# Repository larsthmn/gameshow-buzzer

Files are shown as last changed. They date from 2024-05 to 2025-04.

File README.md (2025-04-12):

# Gameshow Buzzer and Soundboard

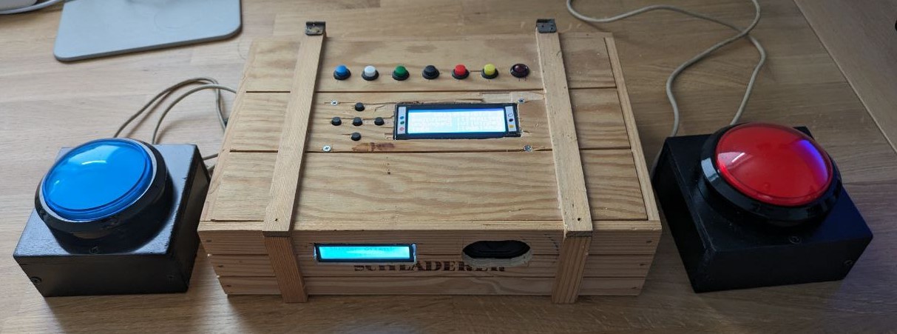
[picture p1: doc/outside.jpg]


## Introduction
This is a fun project for a "device" used to play quizzes with two buzzers (first one pressed lights up).
It's also used as soundboard (you want to insult a player? Just press a button for that).
The sounds are stored as WAV on an SD card.
As I had a 20x4 LCD with navigation buttons left over from my Anet A8 printer, it's got a little menu to navigate through soundboard
pages and configure some stuff.
Sounds are played over a cheap speaker connected to an I2S amplifier.

## Hardware
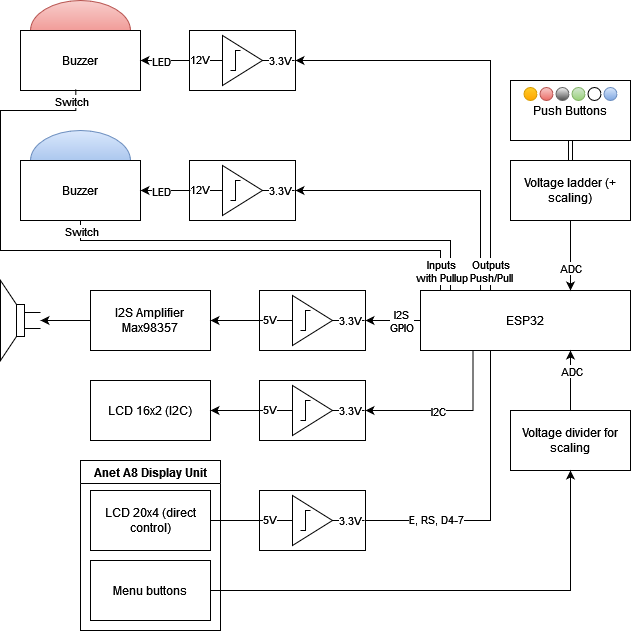
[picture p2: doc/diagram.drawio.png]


Most parts are either leftovers I had or items that can be bought online for a small price. 
Most of them can be replaced by similar components.
 - ESP32 from [here](https://github.com/FKainka/NodeESP_Firmware) (just use any you got lying around)
 - 5V LCD1602 with I2C interface (actually a bit useless)
 - Max98357 I2S 3W Class D Amplifier
 - JCD 1PCS Notebook Speaker Horn 2W 8R
 - PCM5102A I2S DAC for an external speaker (added that after I realized the small cheap one may be overheard with people around).
   You may need to make some solder bridges like [here](https://github.com/pschatzmann/ESP32-A2DP/wiki/External-DAC): 
   Bridge SCK on top, bridge 1, 2, 4 to L and 3 to H on bottom
 - 6pcs Self-Lock /Momentary Pushbutton Switches DS228 DS428 12mm OFF- ON Push (colored)
 - 2x 100mm Big Round Push Button LED Illuminated with Microswitch for DIY Arcade Game Machine Parts 5/12V Large Dome Light Switch
 - 3A Mini DC-DC Buck Step Down Converter Board Module 5V-30V to 5V DC DC Voltage Regulator PCB Board Power Buck Module
 - 20x4 LCD from Anet A8 (schematic [here](https://github.com/ralf-e/ANET-3D-Board-V1.0)) 
 - Bidirectional level shifters 3.3V <-> 5V, must be suitable for I2C
 - Bread boards, cables, some transistors, resistors, caps
 - A large wooden box for the electronics and a small wooden box, painted black, for the buzzers.

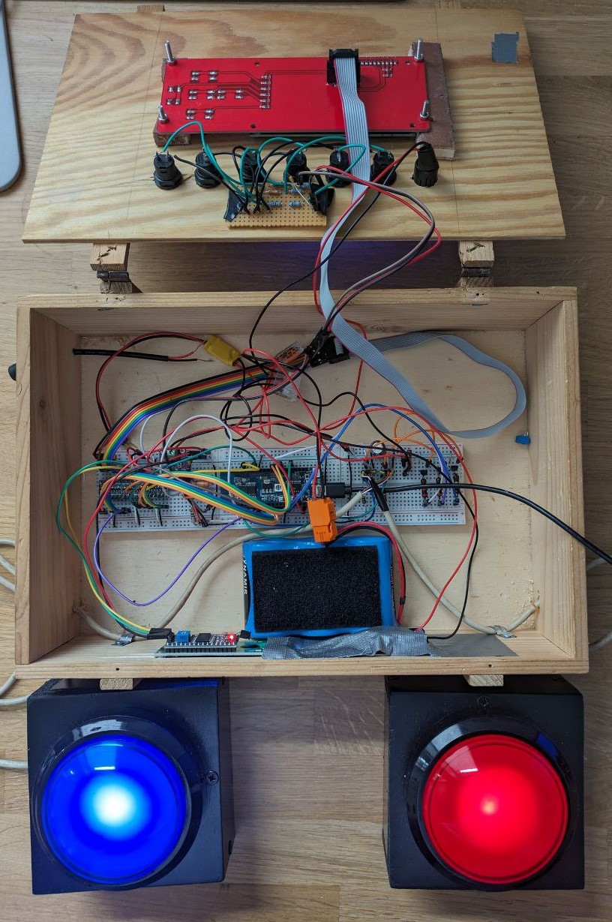
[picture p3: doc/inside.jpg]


Just tingle them together as documented in the Fritzing Sketch:
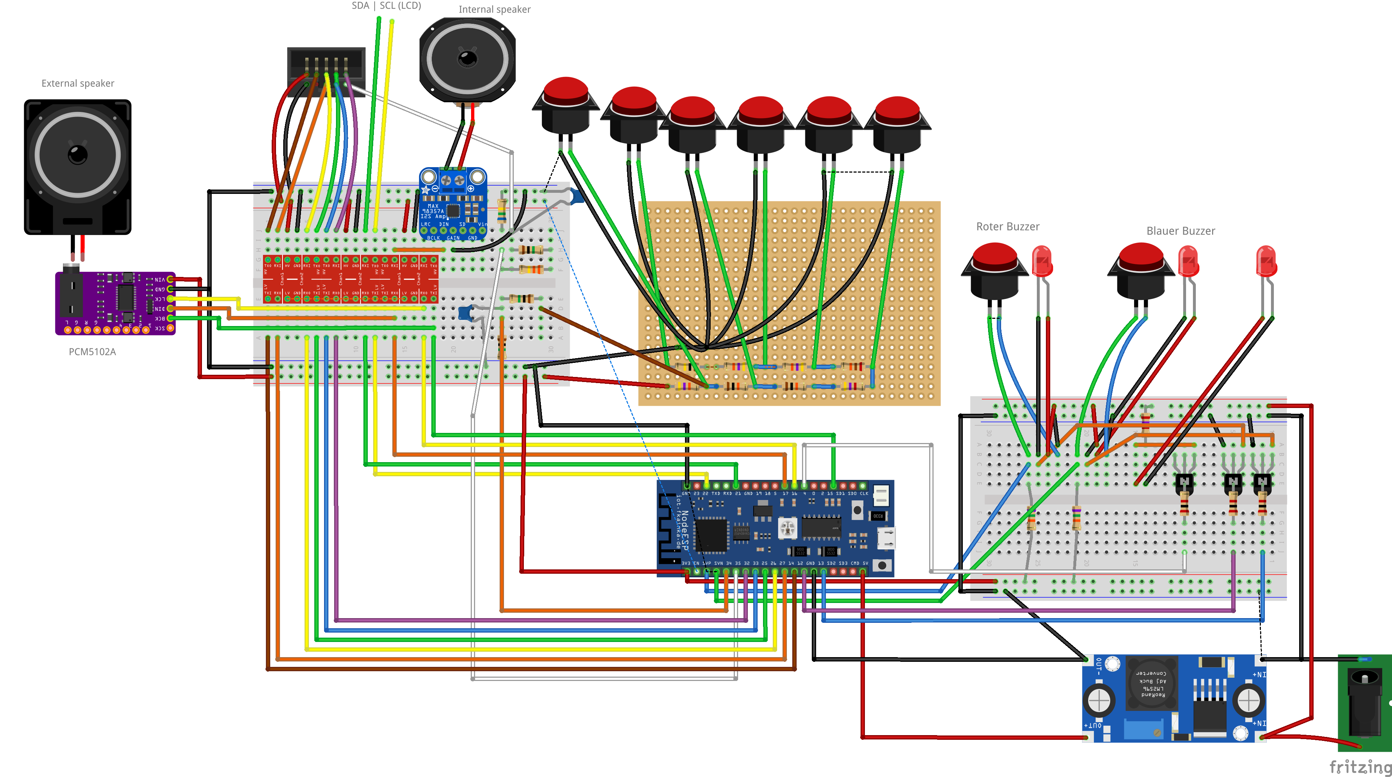
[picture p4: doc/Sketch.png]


To connect many buttons to one input, make a voltage ladder like this:
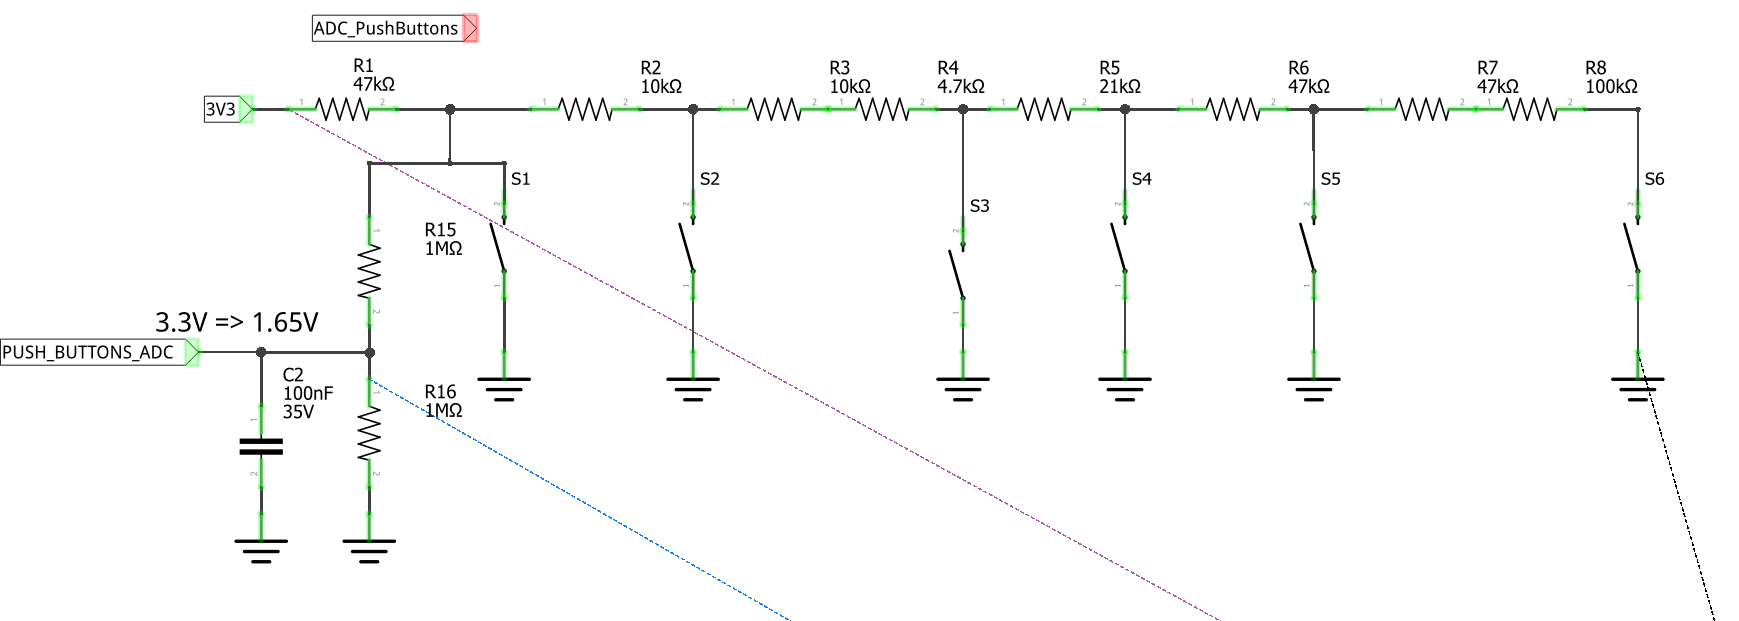
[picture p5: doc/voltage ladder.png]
voltage ladder.png

This is also used in the LCD module from the Anet A8. 
You need to connect these to an ADC input and just measure the values you get for each button.

## Software
### Setup
Use PlatformIO with the platformio.ini and you're good to go. 

### Description
There are a few modules giving us the features we need:

| Source file | Description |
|---|---|
| sounds | Playback of sounds using ESP8266Audio in a separate thread. |
| soundboard | Read the files from the SD card and put them into pages. |
| screen | Calls the screen functions that display something on the 20x4 LCD |
| debugScreen | Screen with some debug output |
| soundboardScreen | Screen with soundboard pages and sounds. This is the most important one. |
| menuScreen | Configuration screen |
| config | Definitions and functions for config variables that are saved to flash |
| input | Read inputs like Push Buttons, Buzzers and menu buttons |
| main | Guess what |

### Sounds
Sounds should be put onto the SD card. Just copy the whole wav dir into the root dir of the SD card.
When adding/editing sounds, it may be convenient to enable the FTP server on the ESP32 (Use the flag `RUN_FTP` if main.cpp for that)
to copy files to the SD card without removing it.
Adhere to the naming scheme of 
```text
{Index}_{Name, max 9 chars}[_optional stuff that shall be ignored].wav
```
for the soundboard sounds. Mono WAV files are recommended as we have only one channel anyway.
The index for the names start at 1.

#### Overview
Use the python script `scripts/soundboard_excel.py` to create an excel file with all soundboard pages and sounds.
This can be used together with the page jump feature to quickly access sounds. 
(Press LCD enter button and then the push buttons from )

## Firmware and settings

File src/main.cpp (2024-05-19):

#define LOG_LOCAL_LEVEL ESP_LOG_VERBOSE

#include <Arduino.h>
#include <Wire.h>

#include <hd44780.h>                       // main hd44780 header
#include <hd44780ioClass/hd44780_I2Cexp.h> // i2c expander i/o class header
#include <SD.h>

#include "pins.h"
#include "sounds.h"

#include "inputs.h"
#include "config.h"
#include "screens/screens.h"

#if RUN_FTP
#include <WiFi.h>
#include "ESP-FTP-Server-Lib.h"
#include "credentials.h"

FTPServer ftp;
#endif

static const char* TAG = "main";
hd44780_I2Cexp lcd16_2(0x27); // declare lcd object: auto locate & auto config expander chip
ScreenManager screens;
enum LastDisplayFunction {
   DISPLAY_BUZZER,
   DISPLAY_RANDOM,
   DISPLAY_INIT
};
static LastDisplayFunction lastDisplayFunction = DISPLAY_INIT;
static bool ftpIsInit = false;

void setup()
{
   Serial.begin(115200);

   while (!SD.begin(SS))
   {
      ESP_LOGE(TAG, "Failed to initialize SD card");
      delay(100);
   }
   ESP_LOGI(TAG, "SD card initialized successfully");

   pinMode(RED_LED_PIN, OUTPUT);
   pinMode(RED_BUZZER_LED, OUTPUT);
   pinMode(BLUE_BUZZER_LED, OUTPUT);

   // Load settings
   config.load();

   soundPlayer.begin();

   inputsInit();

   screens.init();

#if RUN_FTP
   // login into WiFi
   WiFi.begin(WIFI_SSID, WIFI_PASSWORD);
#endif

   lcd16_2.begin(16, 2);
   lcd16_2.setCursor(2, 0);
   lcd16_2.print("Myje stinkt");
   lcd16_2.setCursor(5, 1);
   lcd16_2.print("LOL");
}


void lightFirstBuzzer(bool red, bool blue, bool reset)
{
   enum State
   {
      STATE_WAITING,
      STATE_ANSWERING,
   };
   static uint32_t lastChange = 0;
   static State state = STATE_WAITING;
   static State prevState = STATE_WAITING;
   static bool lastChoiceSameTime = false;
   int timeToAnswerMs = config.getValue(CFG_TIME_TO_ANSWER) * 1000;
   static uint32_t lastBeepAtTimeLeft = 0;

   switch (state)
   {
      case STATE_WAITING:
         if (red || blue)
         {
            state = STATE_ANSWERING;

            // take the one that was pressed, but if both are pressed take the one
            bool chooseRed = red;
            if (red && blue)
            {
               chooseRed = !lastChoiceSameTime;
               lastChoiceSameTime = chooseRed;
            }
            lastDisplayFunction = DISPLAY_BUZZER;
            lcd16_2.clear();
            lcd16_2.setCursor(0, 0);
            if (chooseRed)
            {
               lcd16_2.print("ROT antwortet");
               digitalWrite(RED_BUZZER_LED, HIGH);
               digitalWrite(RED_LED_PIN, HIGH);
               digitalWrite(BLUE_BUZZER_LED, LOW);
            }
            else
            {
               lcd16_2.print("BLAU antwortet");
               digitalWrite(RED_BUZZER_LED, LOW);
               digitalWrite(RED_LED_PIN, LOW);
               digitalWrite(BLUE_BUZZER_LED, HIGH);
            }


            soundPlayer.requestPlayback(SOUND_TIMER_START, SOUND_PRIO_BUZZER_START, config.getValue(CFG_BUZZER_START_VOLUME));
            lastBeepAtTimeLeft = timeToAnswerMs;
         }
         else
         {
            static uint32_t lastBlink = millis();
            if (millis() - lastBlink > 200)
            {
               digitalWrite(RED_LED_PIN, !digitalRead(RED_LED_PIN));
               lastBlink = millis();
            }
         }
         break;
      case STATE_ANSWERING:
      {
         uint32_t blockedSinceMs = millis() - lastChange;
         auto timeLeft = (int32_t)(timeToAnswerMs - blockedSinceMs);
         if (lastBeepAtTimeLeft - timeLeft > 1000 && timeLeft >= 800)
         {
            soundPlayer.requestPlayback(SOUND_TIMER_BEEP, SOUND_PRIO_BUZZER_BEEP, config.getValue(CFG_BUZZER_BEEP_VOLUME));
            lastBeepAtTimeLeft -= 1000;
         }

         lastDisplayFunction = DISPLAY_BUZZER;
         lcd16_2.setCursor(1, 1);
         lcd16_2.print("Timer: ");
         lcd16_2.print((timeLeft) / 1000.0, 1);
         lcd16_2.print("  ");

         if (reset || timeLeft <= 0)
         {
            state = STATE_WAITING;
            digitalWrite(RED_BUZZER_LED, LOW);
            digitalWrite(BLUE_BUZZER_LED, LOW);

            soundPlayer.requestPlayback(SOUND_TIMER_END, SOUND_PRIO_BUZZER_END, config.getValue(CFG_BUZZER_END_VOLUME));

            lastDisplayFunction = DISPLAY_BUZZER;
            lcd16_2.clear();
            lcd16_2.setCursor(1, 0);
            lcd16_2.print("Buzzer offen!");
         }
         break;
      }
      default:
         state = STATE_WAITING;
         break;
   }

   if (prevState != state) lastChange = millis();
   prevState = state;
}

void randomSound() {
   static uint32_t clearDisplayAt = 0;
   static uint32_t nextPlay = 0;
   const char* randomSounds[] = SOUNDS_RANDOM;
   const int numberOfSounds = sizeof(randomSounds) / sizeof(randomSounds[0]);

   if (config.hasChanged(CFG_SOUND_RANDOM_PERIOD) || config.hasChanged(CFG_SOUND_RANDOM_ADD)
       || config.hasChanged(CFG_SOUND_RANDOM_ENABLE))
   {
      ESP_LOGI(TAG, "Reinit random sounds due to config change");
      config.resetHasChanged(CFG_SOUND_RANDOM_PERIOD);
      config.resetHasChanged(CFG_SOUND_RANDOM_ADD);
      config.resetHasChanged(CFG_SOUND_RANDOM_ENABLE);
      nextPlay = 0; // re-init
   }

   if (millis() >= nextPlay && config.getValue(CFG_SOUND_RANDOM_ENABLE))
   {
      if (nextPlay != 0) {
         ESP_LOGI(TAG, "Play random sound");
         soundPlayer.requestPlayback(randomSounds[config.getValue(CFG_SOUND_RANDOM_SELECTION) % numberOfSounds], SOUND_PRIO_RANDOM,
                                     config.getValue(CFG_SOUND_RANDOM_VOLUME));

         lastDisplayFunction = DISPLAY_RANDOM;
         lcd16_2.clear();
         lcd16_2.setCursor(0, 0);
         lcd16_2.write("Schuettet was in");
         lcd16_2.setCursor(0, 1);
         lcd16_2.write("eure Fressluke!");
         clearDisplayAt = millis() + 30000;
      }
      int32_t periodMs = config.getValue(CFG_SOUND_RANDOM_PERIOD) * 60 * 1000L;
      int32_t randomOffsetMs = random(0, config.getValue(CFG_SOUND_RANDOM_ADD) * 60 * 1000L);
      int32_t nextOffset = max(5000, periodMs + randomOffsetMs);
      nextPlay = millis() + nextOffset;
      ESP_LOGI(TAG, "Next random sound in %.2fs (%.2fs + %.2fs)", nextOffset / 1000.0, periodMs / 1000.0,
                    randomOffsetMs / 1000.0);
   }

   if (clearDisplayAt != 0 && millis() > clearDisplayAt)
   {
      // Only clear display if nothing else has written something there in between
      if (lastDisplayFunction == DISPLAY_RANDOM)
      {
         lcd16_2.clear();
         lcd16_2.setCursor(2, 0);
         lcd16_2.write("Vielen Dank,");
         lcd16_2.setCursor(0, 1);
         lcd16_2.write("gerne wieder! 5*");
      }
      clearDisplayAt = 0;
   }
}


void loop()
{
#if RUN_FTP
   if (!ftpIsInit && WiFi.status() == WL_CONNECTED)
   {
      ESP_LOGI(TAG, "Connected to Wifi + init FTP");
      ftp.addUser(FTP_USER, FTP_PASSWORD);
      ftp.addFilesystem("SD", &SD);
      ftp.begin();
      ftpIsInit = true;
   }

   if (ftpIsInit)
   {
      ftp.handle();
   }
#endif

   static InputValues values = {};
   getInputValues(values);

   screens.loop(values);

   lightFirstBuzzer(values.isRedBuzzerPressed, values.isBlueBuzzerPressed, false);

   randomSound();

   delay(5);
}

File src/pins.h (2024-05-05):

//
// Created by Lars on 13.04.2024.
//

#ifndef ESP32_BUZZER_PINS_H
#define ESP32_BUZZER_PINS_H

#include <Arduino.h>

// The IO13 is ADC14

#define PUSH_BUTTONS_ANALOG_PIN GPIO_NUM_34

// LCD connector:
//  ┌─────────────┬───────────────┐
//  │(1) GND black│(2) 5V red     │
//┌─┤(3) NC       │(4) DB4 brown  │
//│ │(5) RS orange│(6) DB5 yellow │
//└─┤(7) E blue   │(8) DB6 green  │
//  │(9) white    │(10)DB7 purple │
//  └─────────────┴───────────────┘

// LCD display from Anet A8 (ok)
#define LCD_RS GPIO_NUM_27
#define LCD_E  GPIO_NUM_33
#define LCD_D4 GPIO_NUM_14
#define LCD_D5 GPIO_NUM_26
#define LCD_D6 GPIO_NUM_25
#define LCD_D7 GPIO_NUM_32
#define LCD_BUTTONS_ANALOG_PIN GPIO_NUM_35

// Second display is on default I2C pins (21: SDA, 22: SCL)

// LED next to the push buttons
#define RED_LED_PIN GPIO_NUM_4

// Buzzers
#define RED_BUZZER_INPUT GPIO_NUM_36
#define BLUE_BUZZER_INPUT GPIO_NUM_39
#define RED_BUZZER_LED GPIO_NUM_12
#define BLUE_BUZZER_LED GPIO_NUM_13

// I2S amplifier
#define I2S_LRC GPIO_NUM_16
#define I2S_BCLK GPIO_NUM_15
#define I2S_DOUT GPIO_NUM_17

#endif //ESP32_BUZZER_PINS_H

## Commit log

2024-05-05 Tried out esphome/ESP32-audioI2S (not good but kept as option)
2024-05-05 Gain to GND
    [Sketch.fzz]
2024-05-05 Added screen switching and base for menu
2024-05-11 Moved FTP init to loop as lazy init to avoid blocking until WiFi is connected (which is not great if there is not WiFi)
    [main.cpp]
2024-05-18 Add documentation
    [Sketch.fzz]
2024-05-18 removed space to spare a char (display too small)
    [Sketch.fzz]
2024-05-19 Added debug/release builds and use ESP logging framework, set red led on buzzer press to high/low
    [debugScreen.cpp, inputs.cpp, main.cpp]
2025-04-12 Added PCM5102A for an external speaker
    [Sketch.fzz]
